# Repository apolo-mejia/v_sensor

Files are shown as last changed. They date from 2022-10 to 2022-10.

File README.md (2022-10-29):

# v_sensor
Estos son archivos del sensor de vibraciones desarrollado en el entorno del proyecto Siracuza:
Los archivos que contiene:
- Archivos de diseño electrónico: Esquematicos, planchas de los PCBs y librerias delos componentes,
- Códigos de programación del micro-procesador,
- Archivos de diseño de la carcaza.

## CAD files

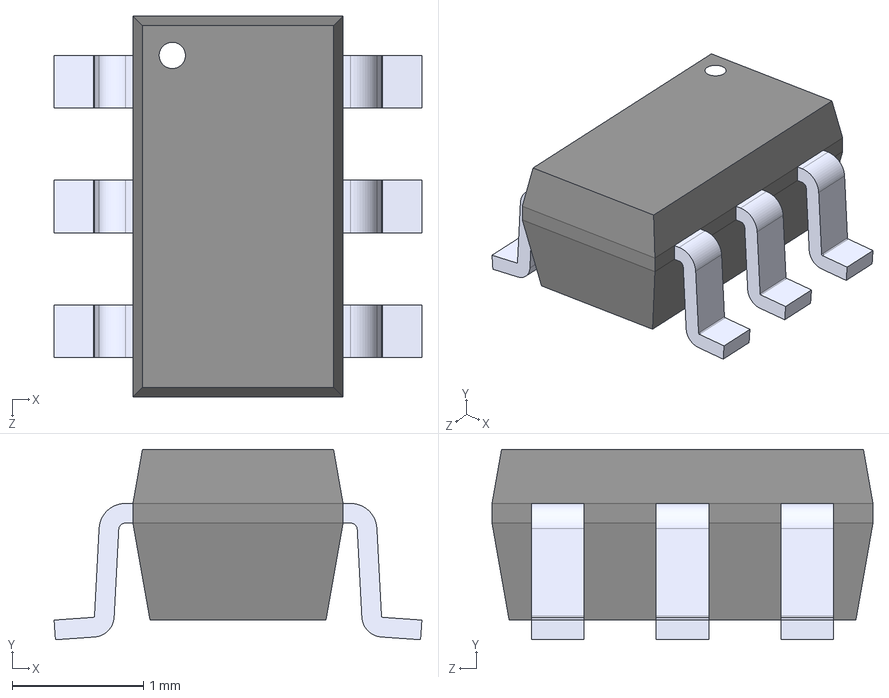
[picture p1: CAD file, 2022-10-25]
Global_Val_Sen/DW01A/DW01A.step
2.80 x 1.45 x 2.90 mm

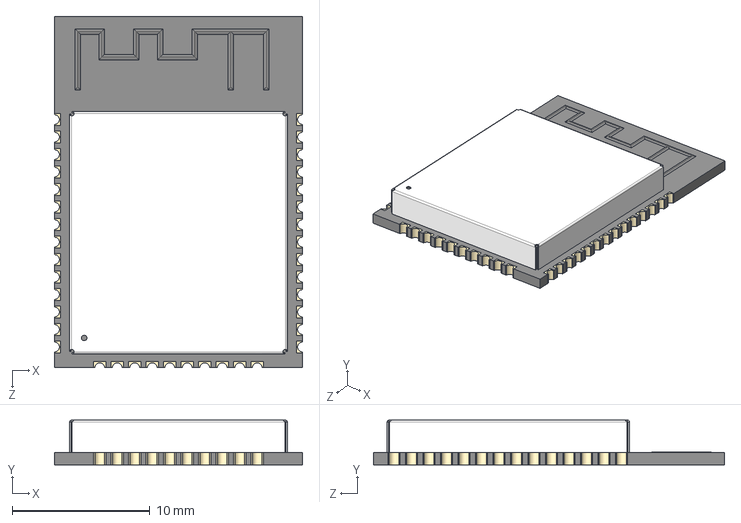
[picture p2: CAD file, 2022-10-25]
Global_Val_Sen/ESP32-WROOM-32D/ESP32-WROOM-32D.step
18.0 x 3.25 x 25.5 mm

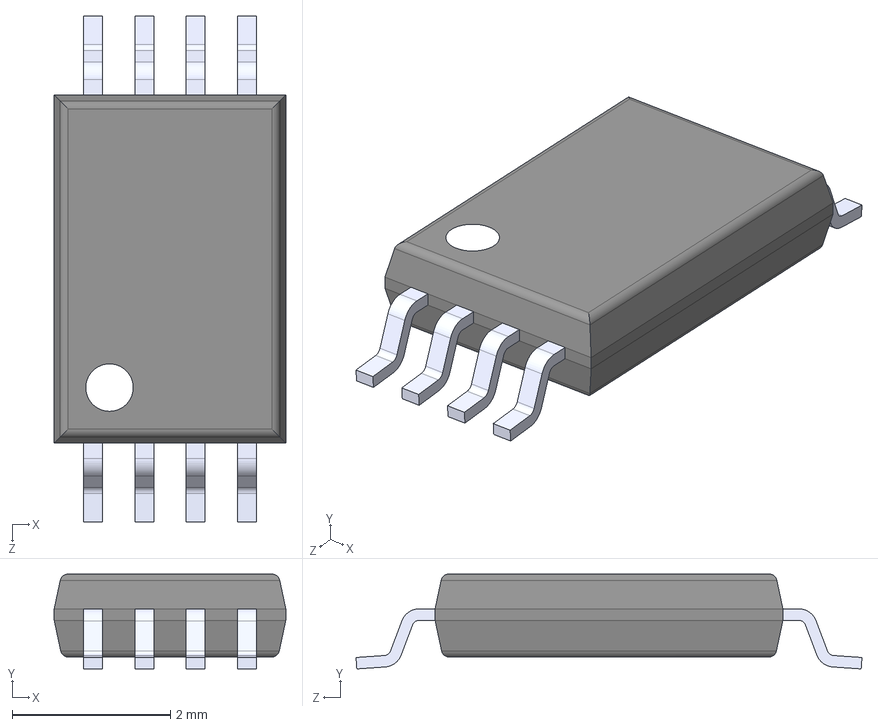
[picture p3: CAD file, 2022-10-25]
Global_Val_Sen/FS8205A/FS8205A.step
2.93 x 1.20 x 6.40 mm

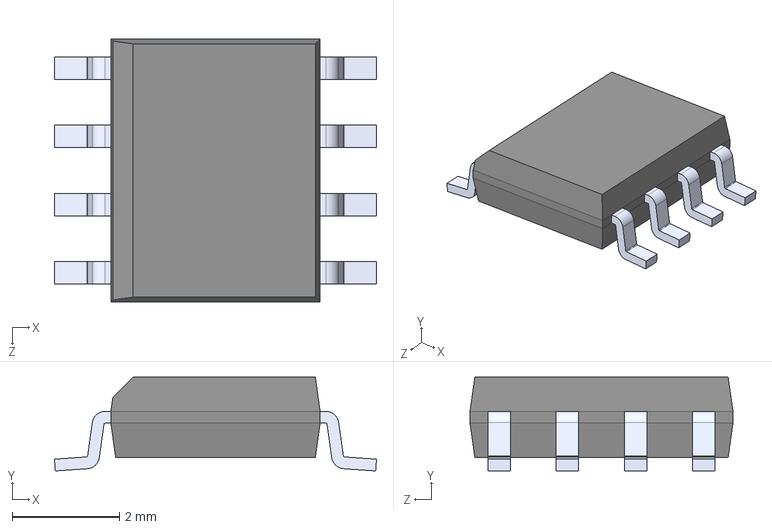
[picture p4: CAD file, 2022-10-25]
Global_Val_Sen/IRF7303/IRF7303.step
6.00 x 1.75 x 4.90 mm

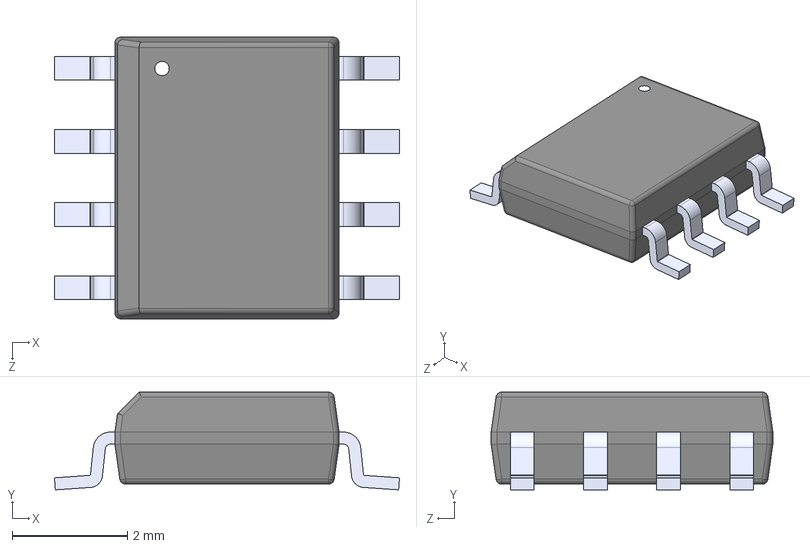
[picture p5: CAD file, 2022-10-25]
Global_Val_Sen/TP4056/TP4056.step
6.00 x 1.70 x 4.90 mm

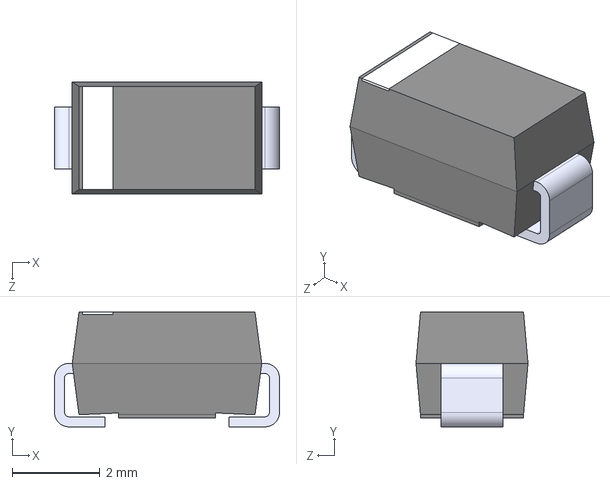
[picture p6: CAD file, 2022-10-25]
Global_Val_Sen/US1M-13/US1M-13.step
5.14 x 2.62 x 2.56 mm

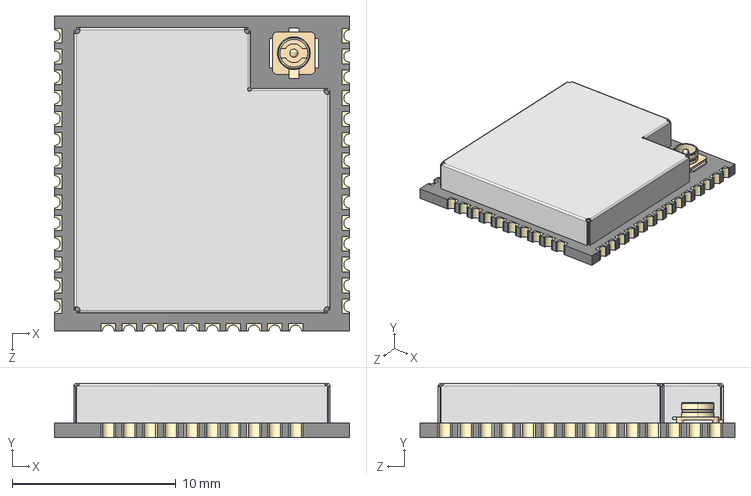
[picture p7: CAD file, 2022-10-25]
Global_Val_Sen/ESP32-WROOM-32D/ESP32-WROOM-32U.step
18.0 x 3.30 x 19.2 mm

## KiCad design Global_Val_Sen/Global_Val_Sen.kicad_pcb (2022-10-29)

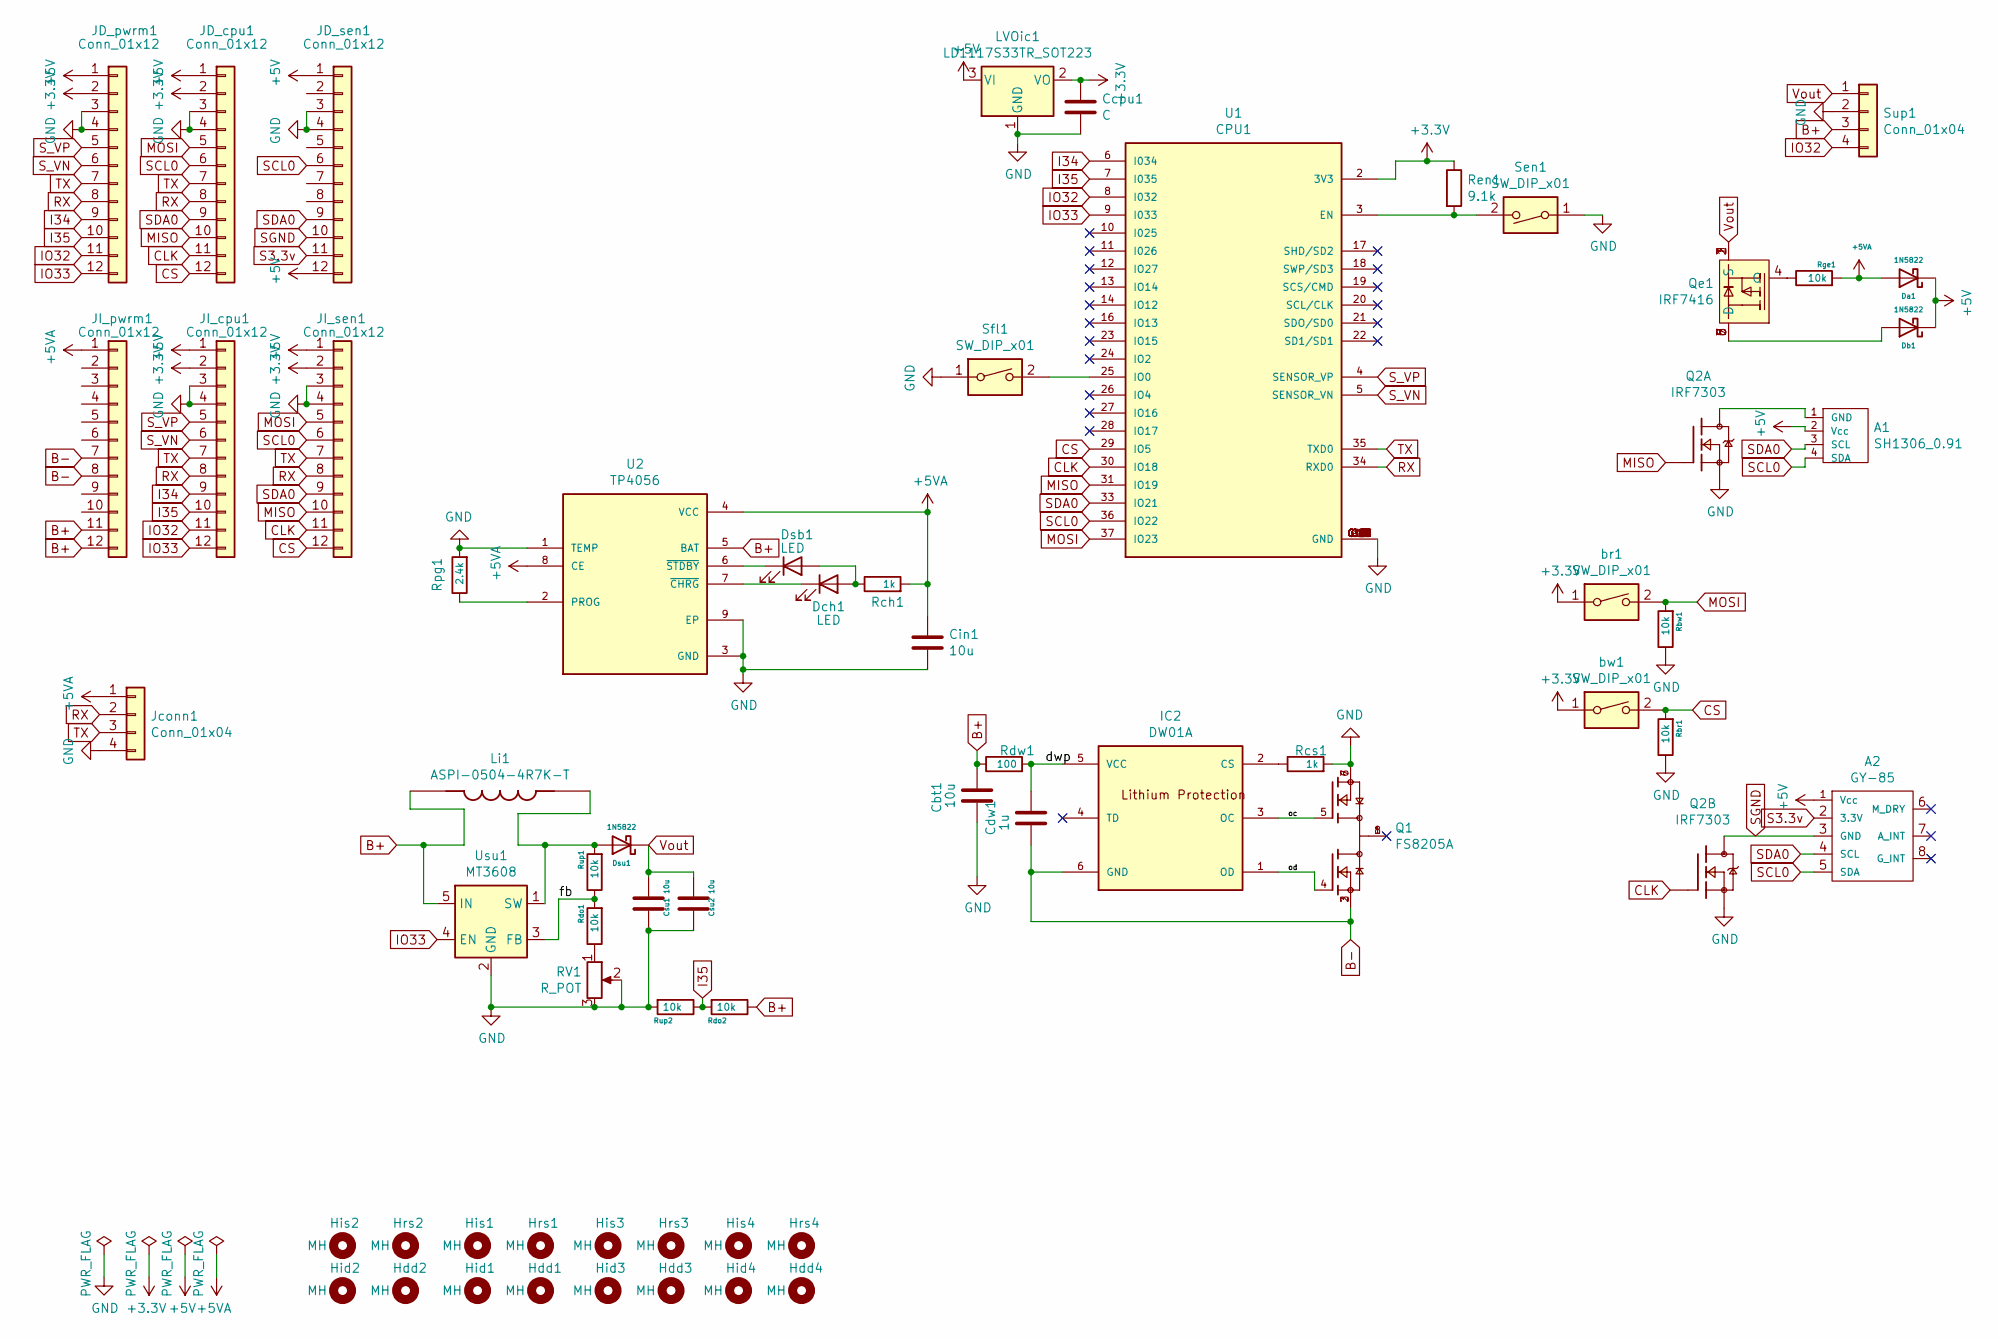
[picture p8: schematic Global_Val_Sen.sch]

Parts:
A1: SH1306_0.91; SSD1306-0.91-OLED-4pin-128x32
A2: GY-85
Cbt1: 10u; CP_EIA-3216-10_Kemet-I_Pad1.58x1.35mm_HandSolder
Ccpu1: C; CP_EIA-3216-10_Kemet-I_Pad1.58x1.35mm_HandSolder
Cdw1: 1u; CP_EIA-3216-10_Kemet-I_Pad1.58x1.35mm_HandSolder
Cin1: 10u; CP_EIA-3216-10_Kemet-I_Pad1.58x1.35mm_HandSolder
Csu1, Csu2: 10u; CP_EIA-3216-10_Kemet-I_Pad1.58x1.35mm_HandSolder
Da1: 1N5822; D_SMA
Db1: 1N5822; D_SMA
Dch1: LED; LED_1206_3216Metric_Castellated
Dsb1: LED; LED_1206_3216Metric_Castellated
Dsu1: 1N5822; D_SMA
Hdd1, Hdd2, Hdd3, Hdd4: MH; MountingHole_2.2mm_M2_DIN965
Hid1, Hid2, Hid3, Hid4: MH; MountingHole_2.2mm_M2_DIN965
His1, His2, His3, His4: MH; MountingHole_2.2mm_M2_DIN965
Hrs1, Hrs2, Hrs3, Hrs4: MH; MountingHole_2.2mm_M2_DIN965
IC2: DW01A; SOT-23-6_Handsoldering
JD_cpu1: Conn_01x12; PinSocket_1x12_P2.00mm_Vertical
JD_pwrm1: Conn_01x12; PinSocket_1x12_P2.00mm_Vertical
JD_sen1: Conn_01x12; PinSocket_1x12_P2.00mm_Vertical
JI_cpu1: Conn_01x12; PinSocket_1x12_P2.00mm_Vertical
JI_pwrm1: Conn_01x12; PinSocket_1x12_P2.00mm_Vertical
JI_sen1: Conn_01x12; PinSocket_1x12_P2.00mm_Vertical
Jconn1: Conn_01x04; PinHeader_1x04_P2.00mm_Vertical
LVOic1: LD1117S33TR_SOT223; SOT-223-3_TabPin2
Li1: ASPI-0504-4R7K-T; IND_ASPI-0504-4R7K-T; PARTREV 06.24.13
Q1: FS8205A; SOP65P640X120-8N; PARTREV 1.7
Q2: IRF7303; SOIC-8
Qe1: IRF7416; SO-8_3.9x4.9mm_P1.27mm
RV1: R_POT; Potentiometer_Bourns_TC33X_Vertical
Rbr1: 10k; R_1206_3216Metric_Pad1.30x1.75mm_HandSolder
Rbw1: 10k; R_1206_3216Metric_Pad1.30x1.75mm_HandSolder
Rch1: 1k; R_1206_3216Metric_Pad1.30x1.75mm_HandSolder
Rcs1: 1k; R_1206_3216Metric_Pad1.30x1.75mm_HandSolder
Rdo1, Rdo2: 10k; R_1206_3216Metric_Pad1.30x1.75mm_HandSolder
Rdw1: 100; R_1206_3216Metric_Pad1.30x1.75mm_HandSolder
Ren1: 9.1k; R_1206_3216Metric_Pad1.30x1.75mm_HandSolder
Rge1: 10k; R_1206_3216Metric_Pad1.30x1.75mm_HandSolder
Rpg1: 2.4k; R_1206_3216Metric_Pad1.30x1.75mm_HandSolder
Rup1, Rup2: 10k; R_1206_3216Metric_Pad1.30x1.75mm_HandSolder
Sen1: SW_DIP_x01; SW_SPST_CK_RS282G05A3
Sfl1: SW_DIP_x01; SW_SPST_CK_RS282G05A3
Sup1: Conn_01x04; PinSocket_1x04_P2.54mm_Vertical
U1: CPU1; ESP32-WROOM-32U; PARTREV V1.9
U2: TP4056; SOP127P600X175-9N
Usu1: MT3608; SOT-23-6
br1: SW_DIP_x01; SW_SPST_CK_RS282G05A3
bw1: SW_DIP_x01; SW_SPST_CK_RS282G05A3

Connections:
+3V3: Ccpu1.1, JD_cpu1.2, JD_pwrm1.2, JI_cpu1.2, JI_sen1.2, LVOic1.2 (VO), Ren1.1, U1.2 (3V3), br1.1, bw1.1
+5V: A1.2 (Vcc), A2.1 (Vcc), Da1.1 (K), Db1.1 (K), JD_cpu1.1, JD_pwrm1.1, JD_sen1.1, JD_sen1.12, JI_cpu1.1, JI_sen1.1, LVOic1.3 (VI)
+5VA: Cin1.1, Da1.2 (A), JI_pwrm1.1, Jconn1.1, Rch1.2, Rge1.2, U2.4 (VCC), U2.8 (CE)
/dwp: Cdw1.1, IC2.5 (VCC), Rdw1.2
/fb: Rdo1.2, Rup1.1, Usu1.3 (FB)
/oc: IC2.3 (OC), Q1.5
/od: IC2.1 (OD), Q1.4
B+: Cbt1.1, JI_pwrm1.11, JI_pwrm1.12, Li1.1, Rdo2.1, Rdw1.1, Sup1.3, U2.5 (BAT), Usu1.5 (IN)
B-: Cdw1.2, IC2.6 (GND), JI_pwrm1.7, JI_pwrm1.8, Q1.2, Q1.3
CLK: JD_cpu1.11, JI_sen1.11, Q2.4, U1.30 (IO18)
CS: JD_cpu1.12, JI_sen1.12, Rbr1.2, U1.29 (IO5), bw1.2
GND: Cbt1.2, Ccpu1.2, Cin1.2, Csu1.2, Csu2.2, JD_cpu1.3, JD_cpu1.4, JD_pwrm1.3, JD_pwrm1.4, JD_sen1.3, JD_sen1.4, JI_cpu1.3, JI_cpu1.4, JI_sen1.3, JI_sen1.4, Jconn1.4, LVOic1.1 (GND), Q1.6, Q1.7, Q2.1, Q2.3, RV1.2, RV1.3, Rbr1.1, Rbw1.1, Rcs1.2, Rpg1.2, Rup2.2, Sen1.1, Sfl1.1, Sup1.2, U1.1 (GND), U1.15 (GND), U1.38 (GND), U1.G.1 (GND), U1.G.2 (GND), U1.G.4 (GND), U1.G.5 (GND), U1.G.6 (GND), U1.G.7 (GND), U1.G.8 (GND), U1.G.9 (GND), U1.G.10 (GND), U1.G.11 (GND), U1.G.12 (GND), U1.G.13 (GND), U1.G.14 (GND), U1.G.15 (GND), U1.G.16 (GND), U1.G.17 (GND), U1.G.18 (GND), U1.G.19 (GND), U1.G.20 (GND), U1.G.21 (GND), U1.G.22 (GND), U2.1 (TEMP), U2.3 (GND), U2.9 (EP), Usu1.2 (GND)
I34: JD_pwrm1.9, JI_cpu1.9, U1.6 (I034)
I35: JD_pwrm1.10, JI_cpu1.10, Rdo2.2, Rup2.1, U1.7 (I035)
IO32: JD_pwrm1.11, JI_cpu1.11, Sup1.4, U1.8 (I032)
IO33: JD_pwrm1.12, JI_cpu1.12, U1.9 (I033), Usu1.4 (EN)
MISO: JD_cpu1.10, JI_sen1.10, Q2.2, U1.31 (IO19)
MOSI: JD_cpu1.5, JI_sen1.5, Rbw1.2, U1.37 (IO23), br1.2
unnamed: A1.1 (GND), Q2.7, Q2.8
unnamed: Db1.2 (A), Qe1.5 (D), Qe1.6 (D), Qe1.7 (D), Qe1.8 (D)
unnamed: Dch1.1 (K), U2.7 (~CHRG)
unnamed: Dch1.2 (A), Dsb1.2 (A), Rch1.1
unnamed: Dsb1.1 (K), U2.6 (~STDBY)
unnamed: Dsu1.2 (A), Li1.2, Rup1.2, Usu1.1 (SW)
unnamed: IC2.2 (CS), Rcs1.1
unnamed: Q1.1, Q1.8
unnamed: Qe1.4 (G), Rge1.1
unnamed: RV1.1, Rdo1.1
unnamed: Ren1.2, Sen1.2, U1.3 (EN)
unnamed: Rpg1.1, U2.2 (PROG)
unnamed: Sfl1.2, U1.25 (IO0)
RX: JD_cpu1.8, JD_pwrm1.8, JI_cpu1.8, JI_sen1.8, Jconn1.2, U1.34 (RXD0)
S3.3v: A2.2 (3.3V), JD_sen1.11
SCL0: A1.4 (SDA), A2.5 (SDA), JD_cpu1.6, JD_sen1.6, JI_sen1.6, U1.36 (IO22)
SDA0: A1.3 (SCL), A2.4 (SCL), JD_cpu1.9, JD_sen1.9, JI_sen1.9, U1.33 (IO21)
SGND: A2.3 (GND), JD_sen1.10, Q2.5, Q2.6
S_VN: JD_pwrm1.6, JI_cpu1.6, U1.5 (SENSOR_VN)
S_VP: JD_pwrm1.5, JI_cpu1.5, U1.4 (SENSOR_VP)
TX: JD_cpu1.7, JD_pwrm1.7, JI_cpu1.7, JI_sen1.7, Jconn1.3, U1.35 (TXD0)
Vout: Csu1.1, Csu2.1, Dsu1.1 (K), Qe1.1 (S), Qe1.2 (S), Qe1.3 (S), Sup1.1

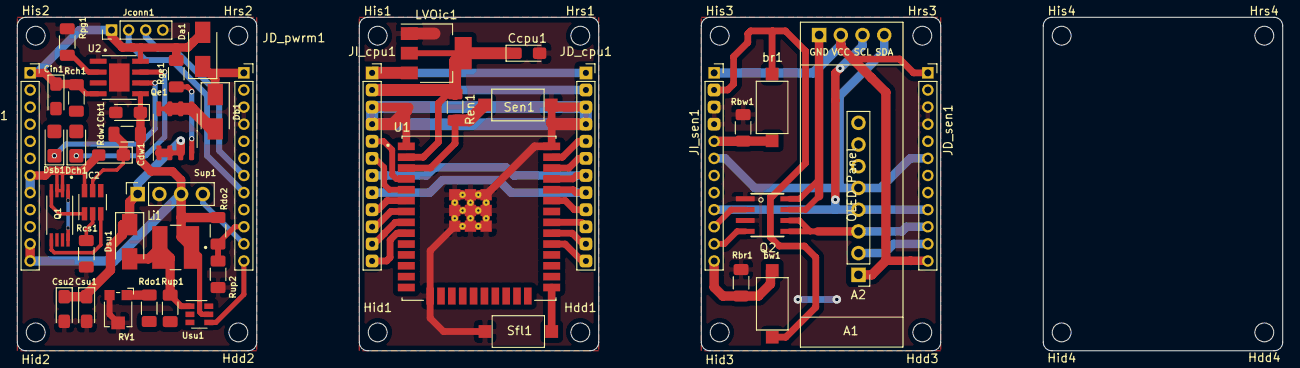
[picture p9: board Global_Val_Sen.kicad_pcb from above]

Board: 2 copper layers, 148.0 x 39.0 mm, 63 parts (0 on the bottom side), 40 nets.

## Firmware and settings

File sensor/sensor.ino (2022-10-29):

git/* Algoritmo que del sensor, esta es el sensor de vibracion*/

/****** -- USO DE LOS PROCESADORES ******/
/****** -- LIBRERIAS -- ******/
#include <esp_now.h>
#include <WiFi.h>
#include <Wire.h>
#include <ADXL345_WE.h>
#include <Adafruit_GFX.h>
#include <Adafruit_SSD1306.h>
/*********************** -- DEFINICIONES -- ************************/
// Direccion del accelerometroADXL345
#define ADXL345_I2CADDR 0x53
// Definiciones de la pantalla
#define SCREEN_WIDTH 128 // OLED display width, in pixels
#define SCREEN_HEIGHT 32 // OLED display height, in pixels
#define SCREEN_ADDRESS 0x3C ///< See datasheet for Address; 0x3D for 128x64, 0x3C for 128x32
#define OLED_RESET     -1 // Reset pin # (or -1 if sharing Arduino reset pin)
/************************* -- SETTINGS -- **************************/
// Creacion del objeto myAcc: "My accelerometro"
ADXL345_WE myAcc = ADXL345_WE(ADXL345_I2CADDR);
// Creacion del objeto display: "My pantalla"
Adafruit_SSD1306 display(SCREEN_WIDTH, SCREEN_HEIGHT, &Wire, OLED_RESET);
/******* -- STRUCTURAS DE DATOS EN COMUNICACION ESP NOW -- *********/
// Estructuras del mensage a enviar
typedef struct struct_message {
  byte mac[6];            // MAC (Own) del emisor
  byte s2write;           // bandera de estados
  int variable;           // que variables vamos a afectar
  int tsample, nsamples;  // tapertuta y numero de muestras
  int pos[2];             // en que posiciones¿afectar?
  float datos[50];        // en si los datos
} struct_message;
// Estructura del mensage a recibir
typedef struct struct_message2 {
  byte request;           // ¿Que necesita apa?
  }struct_message2;

/***********************  -- CONSTANTES -- *************************/
// Pines usados para controlar encendido de perifericos
const int outSen = 18;    // Sensor ON/OFF
const int outScr = 19;    // Pantalla ON/OFF

/********************* -- VARIABLES GLOBALES -- ********************/
// Global Variables
int staSen = HIGH;
int staScr = HIGH;

// Creemos las variables de envio y recepcion de ESP_NOW, 
struct_message data2send;
struct_message2 data2rec;

// MAC Address del Gateway - edit as required
uint8_t broadcastAddress[] = {0x98, 0xCD, 0xAC, 0x49, 0xC4, 0x10};

// Variables de la medidas del sensor
float accx[1750], accy[1750], accz[1750];

// Variables de tiempo
unsigned long timer, start, enlapsed;

// variables para extraer en pruebas
uint8_t mys2write;
byte mac[6];
int meas; // lmeas = 1722,
int count;
int duration=500;
/************ --REVEICED AND SENT CALLBACKS -- ************/

// Peer info
esp_now_peer_info_t peerInfo;

// Callback function called para enviar datos
void OnDataSent(const uint8_t *mac_addr, esp_now_send_status_t status) {
  Serial.print("\r\nLast Packet Send Status:\t");
  Serial.println(status == ESP_NOW_SEND_SUCCESS ? "Delivery Success" : "Delivery Fail");
}

// Callback funtion called when data is Received
void OnDataRecv(const uint8_t * mac,const uint8_t *incomingData, int len) {
  memcpy(&data2rec, incomingData, sizeof(data2rec));
  Serial.print("Bytes received: ");
  Serial.println(len);
  Serial.print("el request que se recive es : ");
  Serial.println(data2rec.request);
}


/************* -- FUNCIONES PARA EL ENVIO DE PAQUETES -- *************/
// Funcion que envia una matriz entera. 
void enviopack(float medida[1750], int lon){
  // Preparemos las variables a enviar con el seccionaminto de los paquetes
  int ini;
  while( ini <= lon ){
    data2send.pos[0] = ini;
    data2send.pos[1] = ini + 50;
    for(int y = data2send.pos[0]; y < data2send.pos[1]; y++){
      data2send.datos[y-ini] = medida[y];
    //  Serial.println(y-ini);
    }
    // Send message via ESP-NOW  -- ahora incluyendo el paquete
    esp_err_t result = esp_now_send(broadcastAddress, (uint8_t *) &data2send, sizeof(data2send)); 
    if (result == ESP_OK) {Serial.println("Sending confirmed");
    }else {Serial.println("Sending error");
    }
    delay(10);
    ini=ini+50;
    // Serial.print("el inicializador es ");Serial.println(ini);
  }
}
/********************* -- FUNCIONES PARA PANTALLA -- ********************/
// Texto grande una Linea hasta 10 caracteres
void OneLine(char caracteres[]) {
  display.clearDisplay();
  display.drawRoundRect(1,1, display.width()-1, display.height()-1, 4, SSD1306_WHITE);
  display.setTextSize(2.5);              // Normal 1:1 pixel scale
  display.setTextColor(SSD1306_WHITE); // Draw white text
  display.setCursor(6, 9);           // Start at point
  display.println(F(caracteres));
  display.display();
  delay(2);
}

// Texto pequeño con dos lineas
void TwoLine(char linea1[], char linea2[]) {
  display.clearDisplay();
  display.drawRoundRect(1,1, display.width()-1, display.height()-1, 4, SSD1306_WHITE);
  display.setTextSize(1);              // Normal 1:1 pixel scale
  display.setTextColor(SSD1306_WHITE); // Draw white text
  display.setCursor(8, 6);             // Start point for a first line
  display.print(F(linea1));
  display.setCursor(8,16);             // Start point for a second line
  display.print(F(linea2));
  display.display();
  delay(2);
}


void setup() {

  // Definamos como salidas digitales de la pantalla y el sensor
  pinMode(outSen, OUTPUT);
  pinMode(outScr, OUTPUT);
  delay(100);

  // Encendamos  la pantalla y el sensor
  digitalWrite(outSen, staSen);
  digitalWrite(outScr, staScr);
  delay(500);
  
  // Set up Serial Monitor
  Serial.begin(115200);


  // Inicio del bus I2C (vamos a colocar los pines trocados
  Wire.begin(22,21);
  Wire.setClock(400000);

  // Inicializacion de la pantalla
  //SSD1306_SWITCHCAPVCC = generate display voltage from 3.3V internally
  if(!display.begin(SSD1306_SWITCHCAPVCC, SCREEN_ADDRESS)) {
    Serial.println(F("SSD1306 allocation failed"));
    for(;;); // Don't proceed, loop forever
  }
  display.display();

  // Iniciemos el accelerador
  if(!myAcc.init()){
    Serial.println("ADXL345 not connected!");
  }
  /* Choose the data rate         Hz
    ADXL345_DATA_RATE_3200    3200
    ADXL345_DATA_RATE_1600    1600
    ADXL345_DATA_RATE_800      800
    ADXL345_DATA_RATE_400      400
    ADXL345_DATA_RATE_200      200
    ADXL345_DATA_RATE_100      100
    ADXL345_DATA_RATE_50        50
    ADXL345_DATA_RATE_25        25
    ADXL345_DATA_RATE_12_5      12.5  
    ADXL345_DATA_RATE_6_25       6.25
    ADXL345_DATA_RATE_3_13       3.13
    ADXL345_DATA_RATE_1_56       1.56
    ADXL345_DATA_RATE_0_78       0.78
    ADXL345_DATA_RATE_0_39       0.39
    ADXL345_DATA_RATE_0_20       0.20
    ADXL345_DATA_RATE_0_10       0.10
  */
  myAcc.setDataRate(ADXL345_DATA_RATE_3200);
  // Configuremoslo en Resolución full pa todos los tiros
  myAcc.setFullRes(true);
  /* Choose the measurement range
    ADXL345_RANGE_16G    16g     
    ADXL345_RANGE_8G      8g     
    ADXL345_RANGE_4G      4g   
    ADXL345_RANGE_2G      2g
  */ 
  myAcc.setRange(ADXL345_RANGE_4G);
/* Uncomment to enable Low Power Mode. It saves power but slightly
    increases noise. LowPower only affetcs Data Rates 12.5 Hz to 400 Hz.
*/
  // myAcc.setLowPower(true);

  // Set ESP32 as a Wi-Fi Station
  WiFi.mode(WIFI_STA);
  // Guardemos la mac del sensor
  WiFi.macAddress(data2send.mac);

  // Initilize ESP-NOW
  if (esp_now_init() != ESP_OK) {
    Serial.println("Error initializing ESP-NOW");
    return;
  }

  // Register the send callback
  esp_now_register_send_cb(OnDataSent);
  
  // Register peer
  memcpy(peerInfo.peer_addr, broadcastAddress, 6);
  peerInfo.channel = 0;
  peerInfo.encrypt = false;
  
  // Add peer        
  if (esp_now_add_peer(&peerInfo) != ESP_OK){
    Serial.println("Failed to add peer");
    return;
  }
  // Register callback function
  esp_now_register_recv_cb(OnDataRecv);
  
  //meas = 0x0007;
  
  Serial.println("Aqui estamos desde el sensor ");
}
void loop() {

  OneLine("H:DEDALO05");

    if ((data2rec.request & 0x01) == 0x01){
      count = 0;
      Serial.println("iniciando la toma...");
      TwoLine("TOMANDO DATOS", "TAREA XX");
      start=millis();
      data2send.tsample = duration;
      enlapsed= start + duration;
      while ( millis() < enlapsed){
        xyzFloat g = myAcc.getGValues(); 
        accx[count] = g.x;
        accy[count] = g.y;
        accz[count] = g.z;
        count++;
      }
    data2send.nsamples=count;
    meas = 0x0007;
    Serial.println("lista la toma");
    TwoLine("DATOS TOMADOS", "TAREA XX");
    data2rec.request = data2rec.request & 0xFE;
    }
    if ((data2rec.request & 0x02) == 0x02){
      if ((meas & 0x0001) == 0x0001){
        TwoLine("ENVIANDO DATOS", "ACCX-TAREA XX");
        data2send.variable = 0x0001;
        enviopack(accx, count);
        meas = meas & 0xFFFE;
      }
      if ((meas & 0x0002) == 0x0002){
        TwoLine("ENVIANDO DATOS", "ACCY-TAREA XX");
        data2send.variable = 0x0002;
        enviopack(accy, count);
        meas = meas & 0xFFFD;
      }
      if ((meas & 0x0004) == 0x0004){
        TwoLine("ENVIANDO DATOS", "ACCZ-TAREA XX");
        data2send.variable = 0x0004;
        enviopack(accz, count);
        meas = meas & 0xFFFB;
      }
    data2rec.request = data2rec.request & 0xFD;
    Serial.print("La variable meas quedo en : "); Serial.println(meas);
    Serial.print("La variable request queda en "); Serial.println(data2rec.request);
    }  
  
  }

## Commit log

2022-10-25 Inicial commit
    [DW01A.step, ESP32-WROOM-32D.step, ESP32-WROOM-32U.step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]
2022-10-29 actualizacion sensor Cod &PCB
    [Global_Val_Sen.kicad_pcb, Global_Val_Sen.sch]
